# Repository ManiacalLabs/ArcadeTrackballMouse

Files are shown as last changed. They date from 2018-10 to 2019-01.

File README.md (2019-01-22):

# Arcade Trackball Mouse

A completely unnecessary, but fun computer mouse using arcade components and a billiard ball.

# Design Files

All printed parts were designed in Fusion 360 and can be viewed and downloaded here: https://a360.co/2Rxvm0l
Or find the STL files in the `Fab` folder.

# Bill of Materials

- [Happ/Atari Trackball](http://www.arcadeshop.com/i/19/2-trackball-unit-white-ball-atari-happ.htm)
- [24mm Buttons](https://www.adafruit.com/product/3432)
- [Quick Connect Button Wires](https://www.adafruit.com/product/1152)
- [#10-24 2-1/4" bolt](https://www.amazon.com/gp/product/B07B7JNY5K/)
- [#10-24 Nut](https://www.amazon.com/gp/product/B078SM2C7N/)
- [Teensy 3.2](https://www.pjrc.com/store/teensy32.html)
- [PCB @ OSHPark](https://oshpark.com/shared_projects/eHG1B3Ws) (Or see PCB folder and KiCAD files)

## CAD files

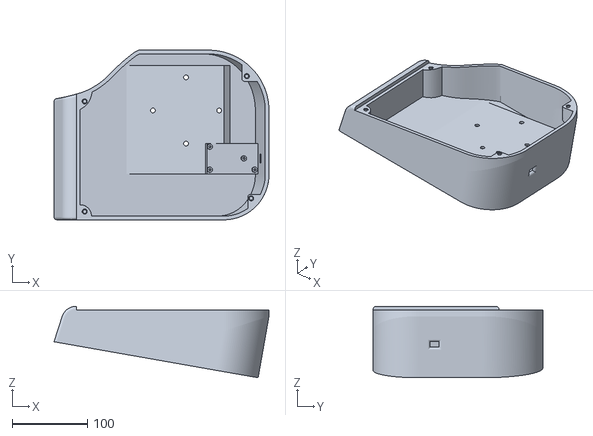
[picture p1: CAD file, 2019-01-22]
Fab/ArcadeMouse_MainCase.stl
285.1 x 225.0 x 94.8

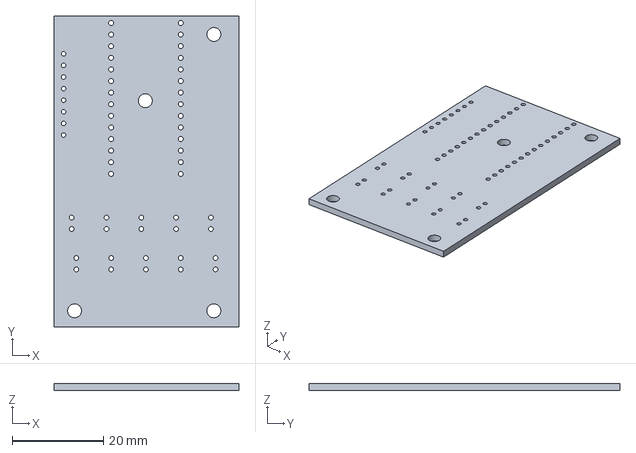
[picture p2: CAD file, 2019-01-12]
PCB/ArcadeTrackballMouse.step
40.5 x 68.0 x 1.60 mm

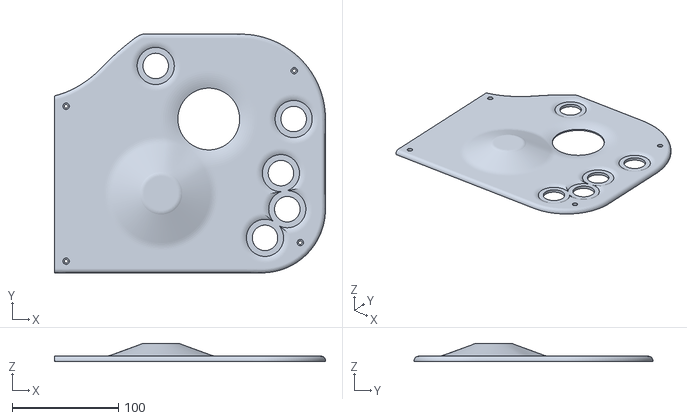
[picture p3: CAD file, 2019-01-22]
Fab/ArcadeMouse_Top.stl
255.4 x 225.0 x 17.0

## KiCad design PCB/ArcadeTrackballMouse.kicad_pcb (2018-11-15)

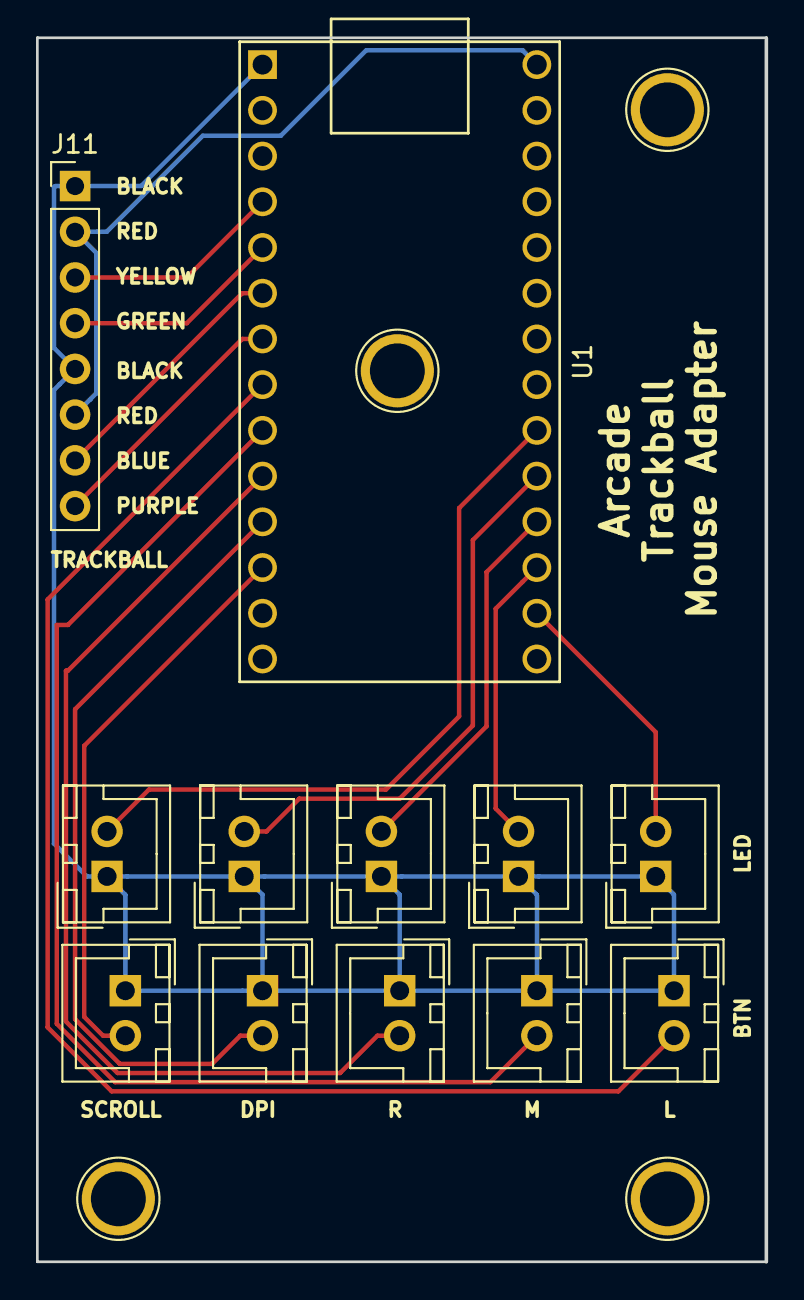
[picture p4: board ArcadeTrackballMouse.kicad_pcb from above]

Board: 2 copper layers, 40.5 x 68.0 mm, 12 parts (0 on the bottom side), 16 nets.

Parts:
J1, J2, J3, J4, J5, J6, J7, J8, J9, J10: Conn_01x02; JST_XH_B02B-XH-A_02x2.50mm_Straight
J11: Trackball; Socket_Strip_Straight_1x08_Pitch2.54mm
U1: Teensy3.2; Teensy30_31_32_LC_NoCenterPads

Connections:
/YELLOW: J11.4, U1.5
BTN_DPI: J4.2, U1.11
BTN_L: J1.2, U1.8
BTN_M: J2.2, U1.9
BTN_R: J3.2, U1.10
BTN_SCROLL: J5.2, U1.12
GND: J1.1, J2.1, J3.1, J4.1, J5.1, J6.1, J7.1, J8.1, J9.1, J10.1, J11.1, J11.5, U1.1
LED_DPI: J9.2, U1.24
LED_L: J6.2, U1.21
LED_M: J7.2, U1.22
LED_R: J8.2, U1.23
LED_SCROLL: J10.2, U1.25
unnamed: J11.3, U1.4
unnamed: J11.7, U1.6
unnamed: J11.8, U1.7
VIN: J11.2, J11.6, U1.33

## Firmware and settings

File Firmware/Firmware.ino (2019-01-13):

#include "Encoder.h"
#include "globals.h"

Encoder enc_h(H_A, H_B);
Encoder enc_v(V_A, V_B);

byte click_states[] = {0, 0, 0};

void do_click(byte i){
    if(btns[i].wasPressed()){
        reset_event();
        click_states[i] = 1;
    }
    else if(btns[i].wasReleased()){
        reset_event();
        click_states[i] = 0;
    }

    // do outside so it's not reliant on state change
    if(!in_pattern){
        set_led(i, btns[i].isPressed());
    }
}

bool scroll_mode = false;
void do_scroll(){
    static byte i = _SCROLL;
    if(btns[i].isPressed()){
        reset_event();
        if(in_pattern) return;
        set_led(i, true);
        scroll_mode = true;
    }
    else if(btns[i].isReleased()){
        if(in_pattern) return;
        set_led(i, false);
        scroll_mode = false;
    }
}

bool dpi_state = false;
void do_dpi(){
    static byte i = _DPI;
    if(btns[i].wasPressed()){
        reset_event();
        if(in_pattern) return;
        dpi_state = !dpi_state;
    }

    if(in_pattern) return;
    set_led(i, dpi_state);
}

int8_t pattern_step = -1;
unsigned long last_pattern = 0;
void do_pattern() {
    if(TimeElapsed(last_pattern, 1000)){
        Serial.println(pattern_step);
        last_pattern = millis();
        for(byte i=0; i<BTNS; i++){
            set_led(pattern_order[i], pattern_step == i);
        }

        pattern_step += pattern_dir;
        if(pattern_step >= BTNS){
            pattern_step = BTNS-2;
            pattern_dir = -1;
        }
        else if(pattern_step < 0){
            pattern_step = 1;
            pattern_dir = 1;
        }
    }
}

void setup()
{
    Serial.begin(115200);
    Mouse.begin();

    setup_btns();
    setup_leds();
}

void loop()
{
    static long h, v;
    static byte mult = MOUSE_MULT_HIGH;

    if(TimeElapsed(last_event, LAST_EVENT_TIMEOUT)){
        in_pattern = true;
        do_pattern();
    }
    else { in_pattern = false; }

    read_btns();

    do_dpi();
    do_scroll();
    if(!scroll_mode) {
        do_click(_LEFT);
        do_click(_MID);
        do_click(_RIGHT);
        Mouse.set_buttons(click_states[_LEFT], click_states[_MID], click_states[_RIGHT]);
    }

    h = enc_h.read();
    v = enc_v.read();
    if (h != 0 || v != 0) {
        reset_event();
        if(scroll_mode){
            Mouse.scroll(v);
        }
        else {
            mult = dpi_state ? MOUSE_MULT_LOW : MOUSE_MULT_HIGH;
            Mouse.move(h * mult, v * mult * -1); // vert is inverted
        }

        // Reset encoder values so always -1/0/1
        enc_h.write(0);
        enc_v.write(0);
    }
}

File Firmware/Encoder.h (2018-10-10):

/* Encoder Library, for measuring quadrature encoded signals
 * http://www.pjrc.com/teensy/td_libs_Encoder.html
 * Copyright (c) 2011,2013 PJRC.COM, LLC - Paul Stoffregen <paul@pjrc.com>
 *
 * Version 1.2 - fix -2 bug in C-only code
 * Version 1.1 - expand to support boards with up to 60 interrupts
 * Version 1.0 - initial release
 *
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
 * THE SOFTWARE IS PROVIDED "AS IS", WITHOUT WARRANTY OF ANY KIND, EXPRESS OR
 * IMPLIED, INCLUDING BUT NOT LIMITED TO THE WARRANTIES OF MERCHANTABILITY,
 * FITNESS FOR A PARTICULAR PURPOSE AND NONINFRINGEMENT. IN NO EVENT SHALL THE
 * AUTHORS OR COPYRIGHT HOLDERS BE LIABLE FOR ANY CLAIM, DAMAGES OR OTHER
 * LIABILITY, WHETHER IN AN ACTION OF CONTRACT, TORT OR OTHERWISE, ARISING FROM,
 * OUT OF OR IN CONNECTION WITH THE SOFTWARE OR THE USE OR OTHER DEALINGS IN
 * THE SOFTWARE.
 */


#ifndef Encoder_h_
#define Encoder_h_

#if defined(ARDUINO) && ARDUINO >= 100
#include "Arduino.h"
#elif defined(WIRING)
#include "Wiring.h"
#else
#include "WProgram.h"
#include "pins_arduino.h"
#endif

#include "direct_pin_read.h"

#if defined(ENCODER_USE_INTERRUPTS) || !defined(ENCODER_DO_NOT_USE_INTERRUPTS)
#define ENCODER_USE_INTERRUPTS
#define ENCODER_ARGLIST_SIZE CORE_NUM_INTERRUPT
#include "interrupt_pins.h"
#ifdef ENCODER_OPTIMIZE_INTERRUPTS
#include "interrupt_config.h"
#endif
#else
#define ENCODER_ARGLIST_SIZE 0
#endif



// All the data needed by interrupts is consolidated into this ugly struct
// to facilitate assembly language optimizing of the speed critical update.
// The assembly code uses auto-incrementing addressing modes, so the struct
// must remain in exactly this order.
typedef struct {
	volatile IO_REG_TYPE * pin1_register;
	volatile IO_REG_TYPE * pin2_register;
	IO_REG_TYPE            pin1_bitmask;
	IO_REG_TYPE            pin2_bitmask;
	uint8_t                state;
	int32_t                position;
} Encoder_internal_state_t;

class Encoder
{
public:
	Encoder(uint8_t pin1, uint8_t pin2) {
		#ifdef INPUT_PULLUP
		pinMode(pin1, INPUT_PULLUP);
		pinMode(pin2, INPUT_PULLUP);
		#else
		pinMode(pin1, INPUT);
		digitalWrite(pin1, HIGH);
		pinMode(pin2, INPUT);
		digitalWrite(pin2, HIGH);
		#endif
		encoder.pin1_register = PIN_TO_BASEREG(pin1);
		encoder.pin1_bitmask = PIN_TO_BITMASK(pin1);
		encoder.pin2_register = PIN_TO_BASEREG(pin2);
		encoder.pin2_bitmask = PIN_TO_BITMASK(pin2);
		encoder.position = 0;
		// allow time for a passive R-C filter to charge
		// through the pullup resistors, before reading
		// the initial state
		delayMicroseconds(2000);
		uint8_t s = 0;
		if (DIRECT_PIN_READ(encoder.pin1_register, encoder.pin1_bitmask)) s |= 1;
		if (DIRECT_PIN_READ(encoder.pin2_register, encoder.pin2_bitmask)) s |= 2;
		encoder.state = s;
#ifdef ENCODER_USE_INTERRUPTS
		interrupts_in_use = attach_interrupt(pin1, &encoder);
		interrupts_in_use += attach_interrupt(pin2, &encoder);
#endif
		//update_finishup();  // to force linker to include the code (does not work)
	}


#ifdef ENCODER_USE_INTERRUPTS
	inline int32_t read() {
		if (interrupts_in_use < 2) {
			noInterrupts();
			update(&encoder);
		} else {
			noInterrupts();
		}
		int32_t ret = encoder.position;
		interrupts();
		return ret;
	}
	inline void write(int32_t p) {
		noInterrupts();
		encoder.position = p;
		interrupts();
	}
#else
	inline int32_t read() {
		update(&encoder);
		return encoder.position;
	}
	inline void write(int32_t p) {
		encoder.position = p;
	}
#endif
private:
	Encoder_internal_state_t encoder;
#ifdef ENCODER_USE_INTERRUPTS
	uint8_t interrupts_in_use;
#endif
public:
	static Encoder_internal_state_t * interruptArgs[ENCODER_ARGLIST_SIZE];

//                           _______         _______
//               Pin1 ______|       |_______|       |______ Pin1
// negative <---         _______         _______         __      --> positive
//               Pin2 __|       |_______|       |_______|   Pin2

		//	new	new	old	old
		//	pin2	pin1	pin2	pin1	Result
		//	----	----	----	----	------
		//	0	0	0	0	no movement
		//	0	0	0	1	+1
		//	0	0	1	0	-1
		//	0	0	1	1	+2  (assume pin1 edges only)
		//	0	1	0	0	-1
		//	0	1	0	1	no movement
		//	0	1	1	0	-2  (assume pin1 edges only)
		//	0	1	1	1	+1
		//	1	0	0	0	+1
		//	1	0	0	1	-2  (assume pin1 edges only)
		//	1	0	1	0	no movement
		//	1	0	1	1	-1
		//	1	1	0	0	+2  (assume pin1 edges only)
		//	1	1	0	1	-1
		//	1	1	1	0	+1
		//	1	1	1	1	no movement
/*
	// Simple, easy-to-read "documentation" version :-)
	//
	void update(void) {
		uint8_t s = state & 3;
		if (digitalRead(pin1)) s |= 4;
		if (digitalRead(pin2)) s |= 8;
		switch (s) {
			case 0: case 5: case 10: case 15:
				break;
			case 1: case 7: case 8: case 14:
				position++; break;
			case 2: case 4: case 11: case 13:
				position--; break;
			case 3: case 12:
				position += 2; break;
			default:
				position -= 2; break;
		}
		state = (s >> 2);
	}
*/
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

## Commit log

2018-11-15 Adding PCB
    [ArcadeTrackballMouse.kicad_pcb, ArcadeTrackballMouse.sch]
2019-01-22 Add STL Files
    [ArcadeMouse_MainCase.stl, ArcadeMouse_Top.stl]
